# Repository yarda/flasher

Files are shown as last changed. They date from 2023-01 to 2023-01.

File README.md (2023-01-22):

Description:
============

This is an attempt to replace the broken Chinese LED driver with the custom
design using PIC12F1572. It originally drove several LEDs built-in in the
hood (cap). There are three modes of operation (four if the "off" is also
counted as the mode) that are switched via the push button (active low):

| Mode | Description |
|---|---|
| 0 | off (stand-by) |
| 1 | blink 80 ms on / 80 ms off |
| 2 | blink 160 ms on / 160 ms off |
| 3 | constant on |

Power supply is 4.5 V (three 1.5 V coin cells). The average LED current drive
is cca. 20 mA. There is a constant current LED drive which fluctuates by
cca. 1 mA which is not visible by the naked eye. The idle power consumption is
very low (cca. 500 nA), thus it can stay in the stand-by (mode 0) on the coin
cells for several years. It drives the LED by the PWM and can tolerate slight
drop off of the supply voltage (battery discharge).

- [Schematic KiCad](https://github.com/yarda/flasher/blob/master/flasher.kicad_sch)
- [Schematic PDF](https://github.com/yarda/flasher/blob/master/flasher.pdf)

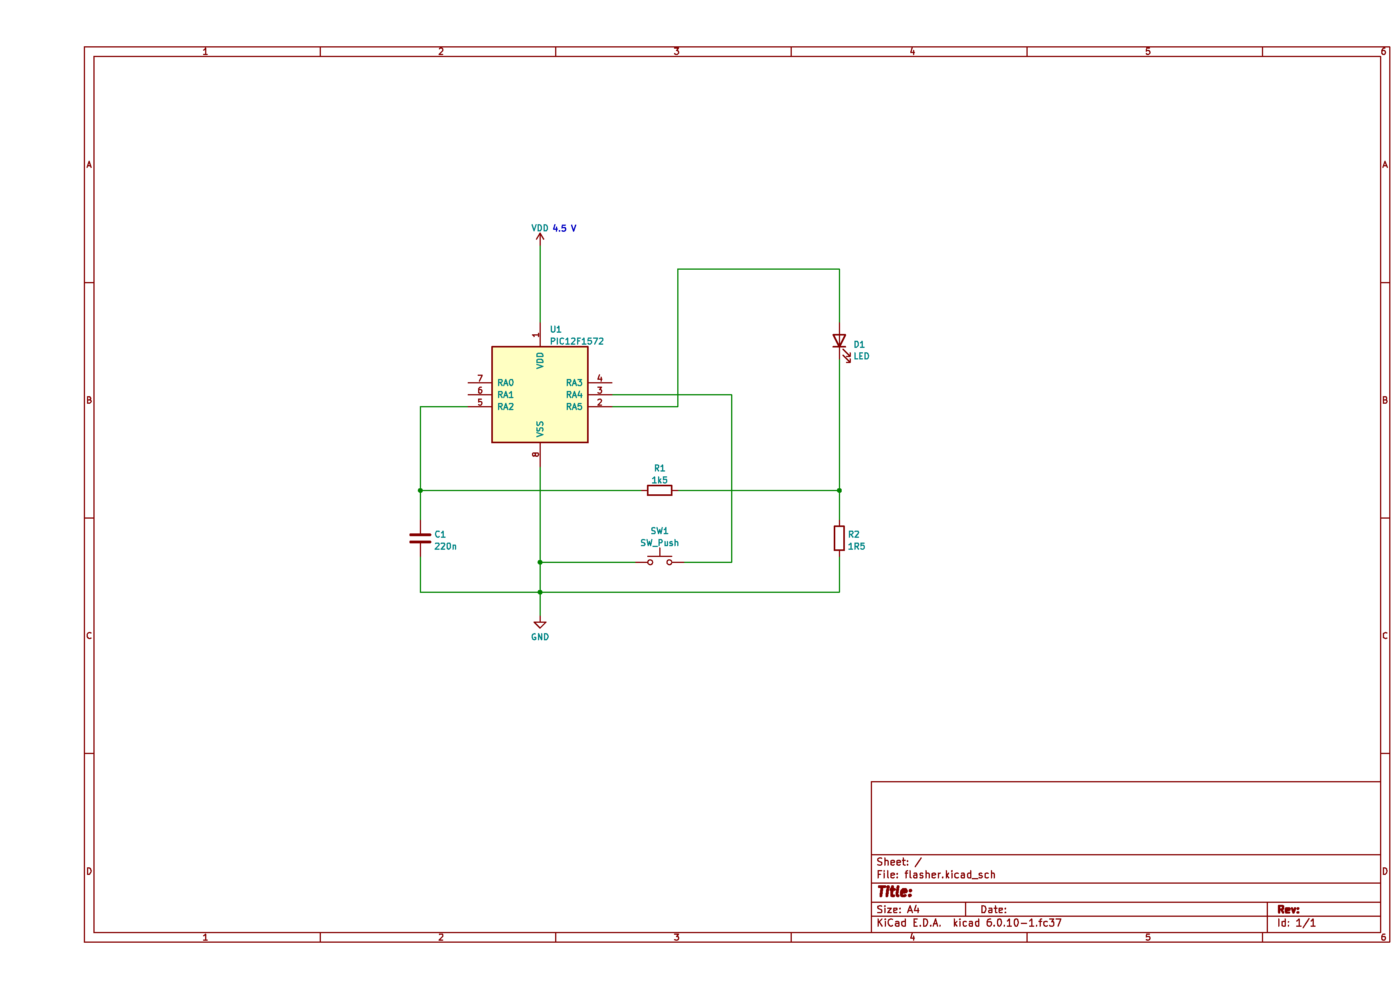
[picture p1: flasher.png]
Schematic PNG Flasher schematic


The feedback loop senses the voltage on the sensing resistor R2 through the
low pass HW filter R1, C1. The voltage is read by the ADC with the constant
voltage reference, thus the sensed voltage corresponds to the current.
The R1, C1 values aren't critical, I used what I had handy. The R1C1 time
constant I used is probably a bit overrated wich resulted in a slow
stabilization (de-stabilization) of the feedback loop (which is OK for the
flasher operated from batteries). Thus it may work correctly even with the
lower R1, C1 values.

There is currently no PCB design because the reference design was hacked onto
the original Chinese PCB (with the removed faulty Chinese ASIC). Feel free
to contribute one :).

The build was tested with the Microchip MPLAB X.

Hacking:
========

Currently it works as the step-down converter. It would be also interesting
improvement to add an inductor (and update the code) to allow it to work
as the step-up converter. In such case it should also keep the current
even if the battery is more discharged.

License:
========

Copyright (C) 2022 Yarda <zbox AT atlas.cz>

This program is free software: you can redistribute it and/or modify
it under the terms of the GNU General Public License as published by
the Free Software Foundation, either version 3 of the License, or
(at your option) any later version.

This program is distributed in the hope that it will be useful,
but WITHOUT ANY WARRANTY; without even the implied warranty of
MERCHANTABILITY or FITNESS FOR A PARTICULAR PURPOSE.  See the
GNU General Public License for more details.

You should have received a copy of the GNU General Public License
along with this program.  If not, see <http://www.gnu.org/licenses/>.

Full text of the license is enclosed in COPYING file.

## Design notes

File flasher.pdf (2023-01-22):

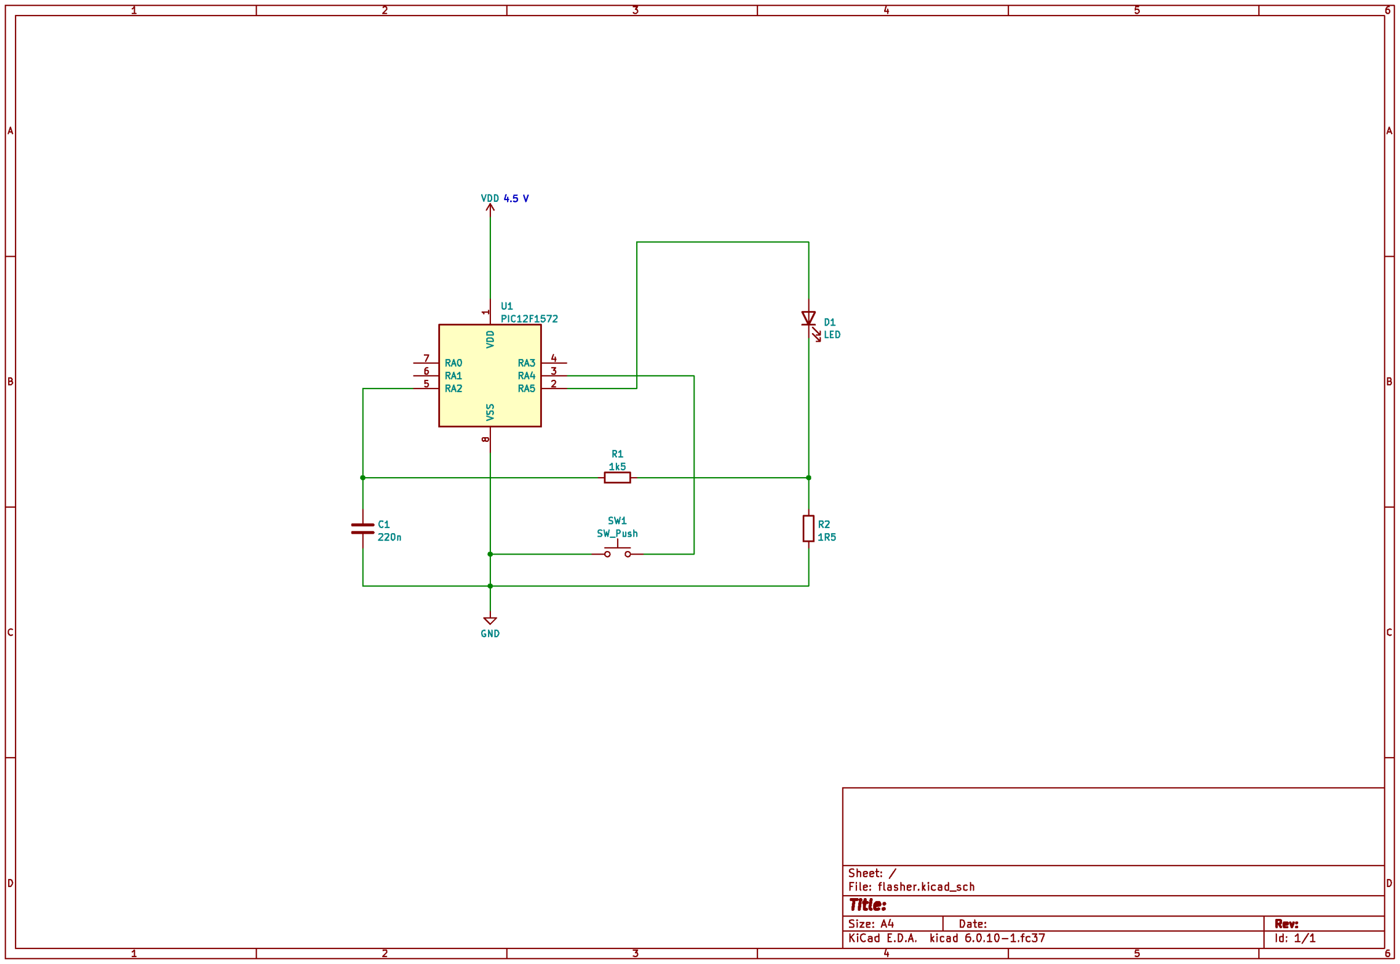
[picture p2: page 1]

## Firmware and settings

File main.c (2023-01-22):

/*
 * File:   main.c
 * Author: yarda
 * Copyright (C) 2022 yarda <zbox AT atlas.cz>
 * MCU: PIC12F1572
 * VDD: 4.5 V
 * Description: PIC12F1572 three mode LED flasher with the constant current LED drive
 * LED drive cca. 20 mA
 * Mode 0: off
 * Mode 1: 80 ms on, 80 ms off
 * Mode 2: 160 ms on, 160 ms off
 * Mode 3: on
 * Modes are changed by the push button
 * Pin RA2: feedback loop sensing input
 * Pin RA4: push button input (active low)
 * Pin RA5: LED drive output
 *
 * Created on October 10, 2022, 1:12 AM
 *
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
 */

#define _XTAL_FREQ 31000

#include <xc.h>

// CONFIG1
#pragma config FOSC = INTOSC    // (INTOSC oscillator; I/O function on CLKIN pin)
#pragma config WDTE = NSLEEP    // Watchdog Timer Enable (WDT enabled while running and disabled in Sleep)
#pragma config PWRTE = ON       // Power-up Timer Enable (PWRT enabled)
#pragma config MCLRE = OFF      // MCLR Pin Function Select (MCLR/VPP pin function is VPP)
#pragma config CP = OFF         // Flash Program Memory Code Protection (Program memory code protection is disabled)
#pragma config BOREN = OFF      // Brown-out Reset Enable (Brown-out Reset disabled)
#pragma config CLKOUTEN = OFF   // Clock Out Enable (CLKOUT function is disabled. I/O or oscillator function on the CLKOUT pin)

// CONFIG2
#pragma config WRT = OFF        // Flash Memory Self-Write Protection (Write protection off)
#pragma config PLLEN = OFF      // PLL Enable (4x PLL enabled)
#pragma config STVREN = ON      // Stack Overflow/Underflow Reset Enable (Stack Overflow or Underflow will cause a Reset)
#pragma config BORV = LO        // Brown-out Reset Voltage Selection (Brown-out Reset Voltage (Vbor), low trip point selected.)
#pragma config LPBOREN = ON     // Low Power Brown-out Reset enable bit (LPBOR is enabled)
#pragma config LVP = ON         // Low-Voltage Programming Enable (Low-voltage programming enabled)

// #pragma config statements should precede project file includes.
// Use project enums instead of #define for ON and OFF.

// 80 ms is cca 620 ticks with 31 kHz clock
#define T80ms 64916
#define T160ms 64296

#define BUTTONM 0x10
#define BUTTONP PORTAbits.RA4
#define LEDP PORTAbits.RA5

#define MOFF 0
#define MFAST 1
#define MSLOW 2
#define MON 3

#define BUFLEN 10

// terget voltage value on the sensing resistor
#define TARGET_VAL 12

#define clear_IOCAF() { \
    IOCAF &= ~BUTTONM; \
}

#define test_IOCAF() \
    ((IOCAF & BUTTONM) == BUTTONM)

#define reload_pwm() { \
    while (PWM1LDCONbits.LDA) \
        ; \
    PWM1LDCONbits.LDA = 1; \
}

#define reload_timer() { \
    TMR1 = timer_preset; \
}

unsigned char mode;
unsigned short timer_preset;
unsigned char adc_val;
unsigned short buf[BUFLEN] = { TARGET_VAL };

void init(void) {
    // RA5 is PWM1
    APFCONbits.P1SEL = 1;
    // 31 kHz internal oscillator
    OSCCON = 0x02;
    // low power sleep mode
    VREGCONbits.VREGPM = 1;
    // explicit init of port A
    PORTA = 0x00;
    LATA = 0x00;
    // RA2 is analog, the rest is digital
    ANSELA = 0x04;
    // BUTTON and RA2 are input, the rest is output
    TRISA = BUTTONM + 0x04;
    // explicitly enable pull-ups control
    OPTION_REG = 0x00;
    // enable pull-up on button
    WPUA = BUTTONM;
    // interrupt on falling edge of BUTTON
    IOCAN = BUTTONM;
    // clear interrupt on change
    clear_IOCAF();
    // enable interrupt on change
    INTCONbits.IOCIE = 1;
    // timer1, fosc/4, no prescaler, timer stopped
    T1CON = 0x00;
    // switch LED off
    LEDP = 0;
    // PWM1 disable, output enable, normal polarity, standard mode
    PWM1CON = 0x40;
    // PWM1 no prescaler, HFINTOSC
    PWM1CLKCON = 0x01;
    // no PWM1 interrupts
    PWM1INTE = 0x00;
    // no trigger for PWM1 reload
    PWM1LDCON = 0x00;
    // PWM1 idependent run mode
    PWM1OFCON = 0x00;
    // PWM1 period
    PWM1PR = 65;
    // PWm1 phase
    PWM1PH = 0;
    // PWM1 duty cycle
    PWM1DC = 10;
    // disable fixed voltage reference, set it to 1,024 V
    FVRCON = 0x42;
    // AN2 (RA2), disable ADC
    ADCON0 = 0x08;
    // right justified, fosc/4, fixed voltage reference
    ADCON1 = 0xc3;
    // no auto conversion trigger
    ADCON2 = 0;
    mode = MOFF;
}

void setup_mode(void) {
    switch (mode) {
        case MOFF:
            PWM1CONbits.EN = 0;
            FVRCONbits.FVREN = 0;
            ADCON0bits.ADON = 0;
            ADCON0bits.ADGO = 0;
            T1CONbits.TMR1ON = 0;
            PIR1bits.TMR1IF = 0;
            break;
        case MFAST:
            PWM1CONbits.EN = 1;
            FVRCONbits.FVREN = 1;
            ADCON0bits.ADON = 1;
            ADCON0bits.ADGO = 1;
            timer_preset = T80ms;
            T1CONbits.TMR1ON = 1;
            reload_timer();
            break;
        case MSLOW:
            PWM1CONbits.EN = 1;
            FVRCONbits.FVREN = 1;
            ADCON0bits.ADON = 1;
            ADCON0bits.ADGO = 1;
            timer_preset = T160ms;
            T1CONbits.TMR1ON = 1;
            reload_timer();
            break;
        case MON:
            PWM1CONbits.EN = 1;
            FVRCONbits.FVREN = 1;
            ADCON0bits.ADON = 1;
            ADCON0bits.ADGO = 1;
            T1CONbits.TMR1ON = 0;
            break;
        default:
            mode = MOFF;
            PWM1CONbits.EN = 0;
            FVRCONbits.FVREN = 0;
            ADCON0bits.ADON = 0;
            ADCON0bits.ADGO = 0;
            T1CONbits.TMR1ON = 0;
            PIR1bits.TMR1IF = 0;
    }
}

unsigned char process_val(unsigned short val) {
    unsigned short avg = 0;
    for (unsigned short x = 0; x < BUFLEN - 1; x++) {
        avg += buf[x];
        buf[x] = buf[x + 1];
    }
    avg += val;
    buf[BUFLEN - 1] = val;
    return (unsigned char) (avg / BUFLEN);
}

void main(void) {
    init();

    while (1) {
        while (!BUTTONP)
            CLRWDT();
        __delay_ms(30);
        clear_IOCAF();
        SLEEP();
        // wait for transient events to stabilize
        __delay_ms(30);
        clear_IOCAF();
        __delay_ms(10);
        if (!test_IOCAF())
            mode++;
        else
            clear_IOCAF();
        setup_mode();
        while (mode > MOFF) {
            if (test_IOCAF()) {
                __delay_ms(30);
                clear_IOCAF();
                if (!BUTTONP) {
                    mode++;
                    if (mode > MON)
                        mode = MOFF;
                    setup_mode();
                }
            }
            if ((mode == MFAST || mode == MSLOW) && PIR1bits.TMR1IF) {
                PIR1bits.TMR1IF = 0;
                reload_timer();
                PWM1CONbits.EN ^= 1;
            }
            if (PWM1CONbits.EN) {
                if (!ADCON0bits.ADGO) {
                    adc_val = process_val(ADRESL);
                    if (adc_val < TARGET_VAL && PWM1DC < 60) {
                        PWM1DC++;
                        reload_pwm();
                    }
                    if (adc_val > TARGET_VAL && PWM1DC > 1) {
                        PWM1DC--;
                        reload_pwm();
                    }
                    ADCON0bits.ADGO = 1;
                }
            }
            CLRWDT();
        }
    }
    return;
}

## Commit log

2023-01-22 Added link to the schematics
2023-01-22 Added PNG schematic
